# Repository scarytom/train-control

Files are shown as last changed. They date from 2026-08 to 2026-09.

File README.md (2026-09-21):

# Train Controller (slot-car hand controller)

We are designing a more ergonomic hand controller for working with minature railway locomotives.  This is an improvement
over the [4QD RBT Hand Control](https://www.4qd.co.uk/product/hand-control-box/).

# Enclosure Design (3D Print) and Assembly
## Files

| File | Purpose | Status |
|---|---|---|
| `design.scad` | **Current working model.** Self-contained (no external files). | Active — work here |
| `profiles/body_outline.dxf` | Ergonomic outline projected from `Left.stl`. Used by `design2.scad`. | Input for v2 |
| `ref/Left.stl`, `ref/Right.stl` | Example printed controller shells (ground-truth ergonomic shape). | Reference |
| `ref/controller3.jpg` | Photo of the reference controller. | Reference |
| `renders/` | Rendered preview PNGs. | Build output |

Recommended: continue in **`design.scad`** — it is a single self-contained file.

## Coordinate convention

- **X** = up/down along the controller length. Top at **−X**, grip / butt at **+X**.
- **Z** = forward / backward.  Front at **+Z**, rear at **−Z**
- **Y** = thickness. The two shell halves separate along **Y**; the profile is centred on Y = 0.

## Face identification

The controller outline has **10 named faces**, each identified by a colour in the
diagram below. This terminology is used throughout the documentation and code.

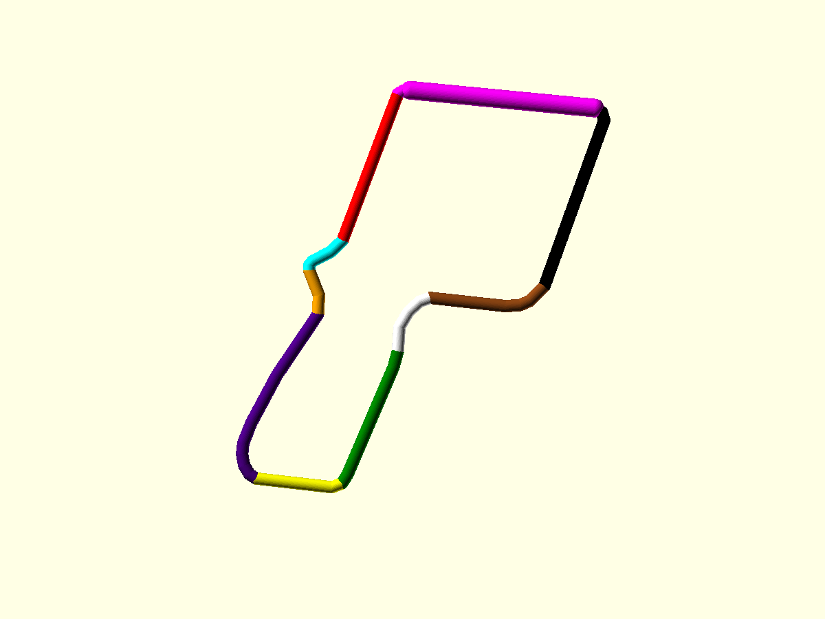
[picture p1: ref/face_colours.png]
Face Colours


| Face | Colour | Points | Description |
|---|---|---|---|
| 1 | Red | 0→1 | **Rear Face** — back of the controller body |
| 2 | Cyan | 1→5 | **Tang Top** — upper surface of the tang |
| 3 | Orange | 5→7 | **Tang Bottom** — lower surface of the tang |
| 4 | Indigo | 7→14 | **Grip Rear** — back of the pistol grip |
| 5 | Yellow | 14→16  | **Grip Butt** — bottom/base of the grip |
| 6 | Green | 16→19  | **Grip Front** — front of the pistol grip |
| 7 | White | 19→23  | **Trigger Throat** — opening where the trigger exits |
| 8 | Brown | 23→27  | **Underbelly** — underside of the controller body |
| 9 | Black | 27→30  | **Front Face** — front of the controller body |
| 10 | Magenta | 30→0 | **Instrument Panel** — raised surface for switches/meter |

The **Instrument Panel** (magenta) is pushed outward by `button_clearance = 20 mm`
along its face normal to provide room for internal components. The adjacent corner
fillets (points 28–29 and 31–33, 0) move with it to blend smoothly into the body.

## What the model produces

`design.scad` produces a complete, print-ready **hollow two-part shell** with
trigger, internal pot mount, control panel and connector:

1. **Ergonomic outline** — the real pistol-grip silhouette, embedded as an inline
   `polygon()` (`outline_points` / `outline_paths`), simplified from `Left.stl`.
2. **Slot removed** — the original finger slot has been deleted from the outline
   (its path is no longer referenced). Its location is preserved as data (see below).
3. **Thickness taper (Y)** — `head_thick = 60 mm` at the head, tapering to
   `grip_thick = 25 mm` at the grip, via `thickness_mask()`.
4. **Raised Instrument Panel** — the angled ~50° face (the switch/meter-mounting
   surface, outline edge 30→31) is pushed outward along its own normal by
   `button_clearance = 20 mm`, with its corner fillets travelling with it so it
   blends smoothly into the body.
5. **Rounded edges** — the whole body is softened via `minkowski()` with a
   sphere of radius `grip_round = 3 mm`, so the edges the hand wraps are
   comfortable. Set `grip_round = 0` to disable (see speed note below).
6. **Hollow shell** — the body is hollowed to a uniform `wall = 1.5 mm` shell
   (`inner_cavity()` = the outer surface shrunk inward by `wall`;
   `body_hollow()` = `body_solid()` minus that cavity). Verified 1.5 mm walls.
7. **Split into two halves** — `left_shell()` / `right_shell()` clip the hollow
   body at the Y = 0 plane into two mating halves.
8. **Mate features** — six perimeter M3 bolt bosses (through-bolt + hex nut
   trap) with alignment spigots
9. **Linear pot mount** — a solid box platform in the LEFT half holding a Bourns
   PTA2043 (35.5×9.5×6.5 mm) along the recorded diagonal pot axis. The pot sits
   on top of the mounting box (30×15×18 mm) with 4 blind holes for the fixing
   pins (1.6 mm diameter, 4 mm deep), positioned per the datasheet (22.8 mm and
   25.2 mm centre-to-centre spacing). Two side clips grip the pot's top edges to
   prevent lifting. Ends are open for wire soldering access.
10. **Trigger + pivot + return spring** — a trigger lever (`trigger_lever()`)
    pivoting at `pivot_pos`: a BENT finger blade exiting the throat up-and-forward
    at ~45°, then curling back to a finger tip near `[0, 30]`, and an actuator arm
    with an elongated fork slot driving the pot lever.
    The pivot pin and spring anchor share a 3 mm rod (`rod_dia`), each captured
    in blind-bore bosses. A return spring hooks a hole in the armature and a
    rod in a body anchor boss, pulling the trigger to rest.
11. **Instrument panel** — holes drilled into the **Instrument Panel** along its normal
    via a face frame built from the face's four corners (`panel_face_place`). The
    LEFT half has four 6 mm toggle holes (master on its own row; horn / reverse /
    lights in a row at 15 mm pitch); the RIGHT half has the LED battery-meter
    cutout (square 25.5 × 2.2 mm slot + two 3.5 mm end holes, 33 mm apart). All
    clear of the bolt bosses.
12. **Thumb button** — a 6 mm push-button hole (`thumb_button_cut()`) on the
    **tang top** at `thumb_pos`, drilled along the local surface normal
    (`thumb_normal`). It sits ON the Y = 0 split, so it is halved into a matching
    semicircle in each shell.
13. **DX16 connector** — a panel-mount aviation socket (16 mm hole, 7 mm thread,
    inner retaining nut) on the **Grip Butt** at `cable_pos`, drilled
    along the local surface normal. Because a threaded connector needs a flat
    full-thickness seat (not a split semicircle), it uses a moulded round **pad**
    (`connector_pad()`, Ø19, 2 mm proud + 3 mm in) on the LEFT shell that crosses
    the seam so the hole stays centred; the RIGHT shell has a matching recess
    (`connector_recess()`). An internal **reinforcing collar**
    (`connector_reinforce()`, LEFT half only) thickens the wall around the socket
    for strength. The Ø16 bore (`connector_hole()`) cuts through both halves.

### Key parameters (top of `design.scad`)

- `grip_thick`, `head_thick` — body thickness (Y) at grip / head.
- `taper_head_x`, `taper_grip_x` — where the thickness taper starts/ends along X.
- `button_clearance` — how far the Instrument Panel is pushed out (room above the pot).
- `button_face_normal`, `button_move_idx` — direction and which outline points move
  (the Instrument Panel + both corner fillets: `[28,29,30,31,32,33,0]`).
- `grip_round` — edge-rounding radius (mm); `0` disables it.
- `wall` — shell wall thickness (mm).
- `screw_boss_pos` — list of `[X, Z]` boss/bolt locations (currently six).
- `screw_clear_dia`, `screw_boss_dia` — bolt clearance hole / boss diameter.
- `screw_head_dia`, `screw_head_depth` — round bolt-head recess (left face).
- `nut_af`, `nut_depth` — hex nut recess across-flats / depth (right face).
- `spigot_dia`, `spigot_len`, `spigot_clear` — boss alignment spigot / fit.
- `pot_len`, `pot_wid`, `pot_hgt` — PTA2043 body envelope (35.5 / 9.5 / 6.5 mm).
- `pot_box_len`, `pot_box_wid`, `pot_box_hgt` — mounting box platform dimensions (30 / 15 / 18 mm).
- `pot_pin_hole_dia`, `pot_pin_hole_depth` — blind hole for fixing pins (1.6 mm dia, 4 mm deep).
- `pot_clip_thick`, `pot_clip_overlap` — side clip dimensions (1.5 mm thick, 1.5 mm overlap).
- `pot_inset` — how far the pot top sits below the split (armature clearance).
- `pot_shift` — shift along the pot long axis (+ve = toward the back/grip).
- `pot_lever_slot_w` — lever clearance slot width (6.5 mm, matches pot lever).
- `rod_dia` — shared metal-rod diameter for BOTH the trigger pivot pin and the
  spring anchor rod (default 3 mm, a common steel dowel / silver-steel size).
- `trigger_thick`, `trigger_hub_dia` — trigger lever thickness / pivot hub.
- `trigger_blade_len`, `trigger_blade_ang` — first blade segment reach/angle out
  of the throat.
- `trigger_blade_knee`, `trigger_blade_tip2` — the bend: knee (near the pivot,
  end of the first segment) and the curled finger tip `[X,Z]` (default `[0,30]`).
- `trigger_arm_aim`, `trigger_arm_extra`, `trigger_arm_w` — actuator arm target,
  extra length, width.
- `trigger_fork_slot`, `trigger_fork_len`, `trigger_fork_pivot_ext` — elongated
  fork slot (width / length / extension toward the pivot) that drives the pot lever.
- `trigger_throat_ext`, `trigger_throat_lowext` — throat cutout swing clearance.
- `pivot_boss_dia`, `pivot_hub_gap`, `pivot_bore_depth` — pivot boss / blind bore.
- `spring_trigger_pos`, `spring_hole_dia` — spring hook hole in the armature.
- `spring_anchor_pos`, `spring_boss_dia`, `spring_bore_depth` — body spring-anchor
  boss + blind bore for the captured rod.
- `ip_TL`, `ip_TR`, `ip_BL`, `ip_BR` — the four corners of the Instrument Panel
  (ground-truth coordinates); the `panel_face_place(u,v)` frame is built from them.
- `toggle_hole_dia`, `panel_drill` — toggle hole diameter / drill depth.
- `toggle_master_u`, `toggle_master_v` — master switch position (upper row).
- `toggle_row_u`, `toggle_row_v` — horn / reverse / lights positions (lower row).
- `meter_slot_l`, `meter_slot_w`, `meter_end_holes`, `meter_hole_span`,
  `meter_u`, `meter_v_right` — LED battery-meter slot + end-hole geometry / placement.
- `thumb_pos`, `thumb_dia`, `thumb_normal`, `thumb_drill` — thumb-button hole
  centre `[X,Z]`, diameter (6 mm), local surface normal, and drill depth. The
  hole is centred on Y = 0 so it splits into a semicircle per shell.
- `cable_pos`, `cable_normal` — DX16 connector centre `[X,Z]` on the grip butt
  and its local outward surface normal (the drilling / socket axis).
- `conn_hole_dia`, `conn_pad_dia`, `conn_pad_proud`, `conn_pad_y` — DX16 bore
  (16 mm), pad diameter (19 mm), pad proud height, and total pad length.
- `conn_reinf_dia`, `conn_reinf_len` — internal reinforcing collar diameter /
  inward depth (LEFT half only). `conn_recess_clear` — right-shell recess fit.
- `part_to_render` — `left_shell`, `right_shell`, `trigger`, `export_stl`,
  `partial_exploded_assembly`, `closed_assembly`, `exploded_assembly`.

## How to render

From the project root (paths in the file are relative):

```bash
# quick preview (isometric)
openscad -o renders/iso.png --camera=200,-260,150,-5,0,5 --viewall design.scad

# clean orthographic side view (the ergonomic silhouette)
openscad -o renders/side.png --camera=0,300,0,0,0,0 --viewall --projection=o design.scad

# export the print-ready plate (all three parts, print orientation)
openscad -o stl/export_plate.stl --render -D 'part_to_render="export_stl"' design.scad
```

Tip: `--viewall` frames the model automatically; `--projection=o` gives a true
orthographic view (best for judging profiles).

## Assembly & fasteners

- **Bolts:** six M3 through-bolts (`screw_boss_pos`). Each drops into a round
  head recess on the LEFT outer face, through a 3.4 mm clearance hole, into a
  hex **nut trap** (`nut_af = 5.5 mm` A/F) on the RIGHT face. Right-half
  **spigots** register into left-half counterbores for alignment.
- **Rods:** the trigger pivot pin and the spring anchor share one `rod_dia`
  (3 mm) steel rod, each captured in blind-bore bosses.
- **Print plate:** `part_to_render = "export_stl"` lays all three parts on the
  bed in print orientation (left shell −90°, right shell / trigger +90° about X),
  each on `Z = 0` and spaced along Y. Each part is manifold (`Simple: yes`).
  The `left_shell` / `right_shell` / `trigger` modes export a single part in its
  native orientation.

## Notes

- The inline outline is a simplified version of the DXF (49 points via
  Douglas-Peucker, ~0.3 mm tolerance). Regenerate with a tighter tolerance if a
  closer match to the original mesh is ever needed.
- The pot axis is diagonal (~−51°); the slide pot mounts at that angle.
- Edge rounding uses `minkowski()`, which needs a full CGAL render
  (`openscad --render ...`) and is slow (~15–30 s). For fast iteration while
  working on other features, set `grip_round = 0`, then restore it for final
  renders / export.

## TODO

### ~~1. Identify the faces~~ ✓ DONE
See [Face identification](#face-identification) section above.

### ~~2. Narrower gap for the trigger lever~~ ✓ DONE
- The trigger lever is 6mm thick (`trigger_thick`), with 0.5mm clearance per side
- Total slot width = 7mm (set by `pivot_hub_gap = trigger_thick/2 + 0.5`)

### ~~3. Refine the pot mounting~~ ✓ DONE
- ✓ Updated pot dimensions to PTA2043: 35.5mm × 9.5mm × 6.5mm
- ✓ Created solid box platform (30mm × 15mm × 18mm) with 4 blind holes for fixing pins
- ✓ Pin holes are 1.6mm diameter (tight fit for 1.5mm pins), 4mm deep
- ✓ Pin spacing: 22.8mm left side, 25.2mm right side (per datasheet)
- ✓ Added 4 clips (3mm wide each) to grip the pot top and prevent lifting
- ✓ Ends remain open for wire soldering access
- ✓ Pot moved 6mm closer to front (black) face (`pot_shift` changed to -1)
- ✓ Trigger pivot moved to align with pot position
- ✓ Trigger blade straightened with bend at [-10, 10], tip at [0, 25]
- ✓ Throat cutout extended 5mm toward black face

### ~~4. move the hub for the trigger spring~~ ✓ DONE
- ✓ Moved spring anchor to [-24.5, -38.5] - near rear (red) face, in line with pot end

### ~~5. Horn buttons~~ ✓ DONE
- ✓ Added 2 horn buttons, one on each side of the controller
- ✓ 5mm mounting holes (per BOM)
- ✓ Mounted on the rear (red) face, close to the tang top (cyan) face
- ✓ Position: [-6, -32] X,Z with Y offset of ±11mm

### ~~6. power switch~~ ✓ DONE
- ✓ Changed from toggle to slide switch
- ✓ 2x 2.5mm fixing holes, 19mm centre-to-centre
- ✓ 4.5mm x 10mm central slot
- ✓ Positioned on its own on the left side of the Instrument Panel

### ~~7. lights / reverse switch~~ ✓ DONE
- ✓ Reduced from 3 toggles to 2 (removed horn select switch)
- ✓ Toggles now occupy top and bottom positions (middle hole removed)
- ✓ Updated hole size to 6.5mm (per BOM)
- ✓ Added 2.5mm locking lug hole, 6.5mm above each main hole

### ~~8. Shorten trigger slightly~~ ✓ DONE
- ✓ Trigger blade shortened by 5mm (from 25mm to 20mm)

### ~~9. Trigger slot.~~ ✓ DONE
- ✓ Trigger fork slot widened to 6.5mm (was 4.5mm)
- ✓ Slot length reduced to 2.5mm (was 6mm)

### ~~10. Grip size~~ ✓ DONE
- ✓ Extended grip by 25mm toward the butt (yellow) face
- ✓ Adjusted screw boss positions for longer grip

### ~~11. socket mounting~~ ✓ DONE
- ✓ Replaced round connector pad with square slot for 24mm x 20mm metal plate
- ✓ Slot includes 1.3mm clearance for plate thickness
- ✓ Inner cavity 22mm x 19mm x 8mm for connector body
- ✓ Thickened butt wall to 6mm to accommodate slot

### ~~12. cable tidy~~ ✓ DONE
- ✓ Added 4 cable tie eyes (half-torus loops) on inner walls of both shells
- ✓ Eyes positioned along cable route from butt to head, away from trigger
- ✓ Eyes use thickness_at_x() function to position correctly in tapered regions
- feel free to suggest other cable management solutions that might work better

### ~~13. button caps~~ ✓ DONE
- ✓ Created button_cap() module with rounded donut-rim top for comfort
- ✓ Friction-fit socket for 2.5mm button stem, 3mm deep
- ✓ Test plate with 8 caps at 4 hole sizes (2.3, 2.4, 2.5, 2.6mm) for fit testing
- ✓ Render with part_to_render = "button_cap" or "button_cap_test_plate"

### 14. discuss joining the 2 halves
- the joint we have between the 2 halves gives some flex around the joint, particularly on front (black) face
- discuss ways to improve the joint

# Circuit Design and Parts

## Circuit References
https://www.4qd.co.uk/docs/din-socket-wiring/
https://www.4qd.co.uk/docs/rbt-plug-alignment/
https://www.4qd.co.uk/docs/rbt-circuit-diagram/

## BOM
### DPST main on/off switch
- DPDT 2-Position On-On Mini Slide Switch
- https://www.bitsboxuk.com/index.php?main_page=product_info&products_id=869
- 2x 2.5mm fixing holes 19mm centre-to-centre
- 4.5mm x 10mm slot central longways between fixing holes 

### SPST lights switch
- multicomp 1MS2T6B11M1QE Flat Toggle Switch, SPDT
- https://cpc.farnell.com/multicomp-pro/1ms1t6b11m1qe/switch-spdt/dp/SW02863
- can substitute Round Toggle Switch, SPST
- https://www.bitsboxuk.com/index.php?main_page=product_info&products_id=872
- 6.5mm mounting hole, with a 2.5mm hole placed 6.5mm above it (centre-to-centre) for the locking lug

### SPST reverse switch
- same as lights switch

### Momentary Horn Buttons
We use two SPDT momentary push buttons in a mechanical interlock.
- multicomp 8MS8P1B05M1QES (has a 2.5mm diameter button)
- https://cpc.farnell.com/multicomp-pro/mc8ms8p1b05m1qes/switch-spdt-on-mom-solder/dp/SW05800
- 5mm mounting hole

### Slide potentiometer for accelerator
- Bourns PTA Range - PTA2043-2010CIB103
- 10k linear single gang slide pot
- https://www.bitsboxuk.com/index.php?main_page=product_info&products_id=3247
- https://www.bourns.com/docs/Product-Datasheets/pta.pdf
- 35.5mm long x 9.5mm wide x 6.5mm deep
- slide has a 20mm range
- slide lever is 10mm tall x 5mm wide x 1.75mm thick
- 4x 1.5mm wide, 3mm tall fixing pins on the underside, a pair on each side
- fixing pins are centre-to-centre 22.8mm apart on the left side, 25.2mm apart on the right side
- wires attach to 0.8mm pins at both ends on the underside, so these must be accessible 

### Diodes
- 1N4001 Rectifier Diode 1A 50V
- https://www.bitsboxuk.com/index.php?main_page=product_info&products_id=1888

### Battery meter (BCM)
- Simple voltage divider – c/f
- https://www.4qd.co.uk/product/battery-condition-meter/
- 2x 3.5mm fixing holes 33mm centre-to-centre
- 25.5mm x 2.2mm slot central longways between fixing holes

### 8-core cable
- 7 x 0.2mm multicore cable
- https://cpc.farnell.com/pro-elec/pelb0640/cable-7-2-8a-unshielded-black/dp/CB22630
- https://www.4qd.co.uk/product/control-cable-multicore/
- https://www.amazon.co.uk/gp/product/B005EHZ6UI
- https://www.bitsboxuk.com/index.php?main_page=product_info&products_id=1496

### 8-pin aviation connectors (GX16)
- https://cpc.farnell.com/pro-signal/av19318/multipole-panel-plug-8p/dp/AV19318
- https://cpc.farnell.com/pro-signal/av19305/multipole-socket-8-pole/dp/AV19305
- https://www.amazon.co.uk/gp/product/B07VNKZB65
- https://www.aliexpress.com/item/1005006731992794.html
- 15mm Cutout diameter

### Pins
- https://www.amazon.co.uk/dp/B0DBYCCZ2J

### Spring
- https://cpc.farnell.com/duratool/d01893/spring-set-200pc/dp/FN02651

### bolts
- https://www.amazon.co.uk/dp/B0DGSY35WC
- https://www.amazon.co.uk/dp/B0D8SG7R6F

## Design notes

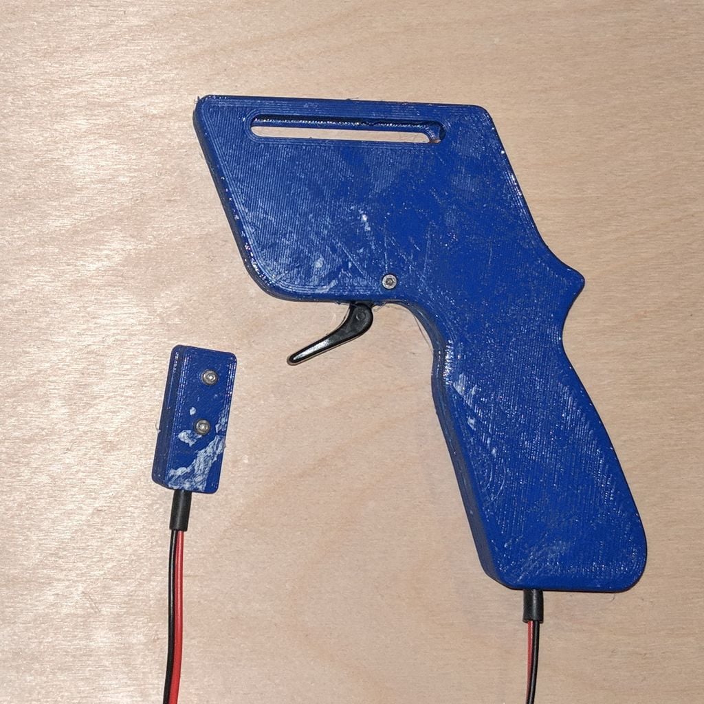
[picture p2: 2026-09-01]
ref/controller3.jpg

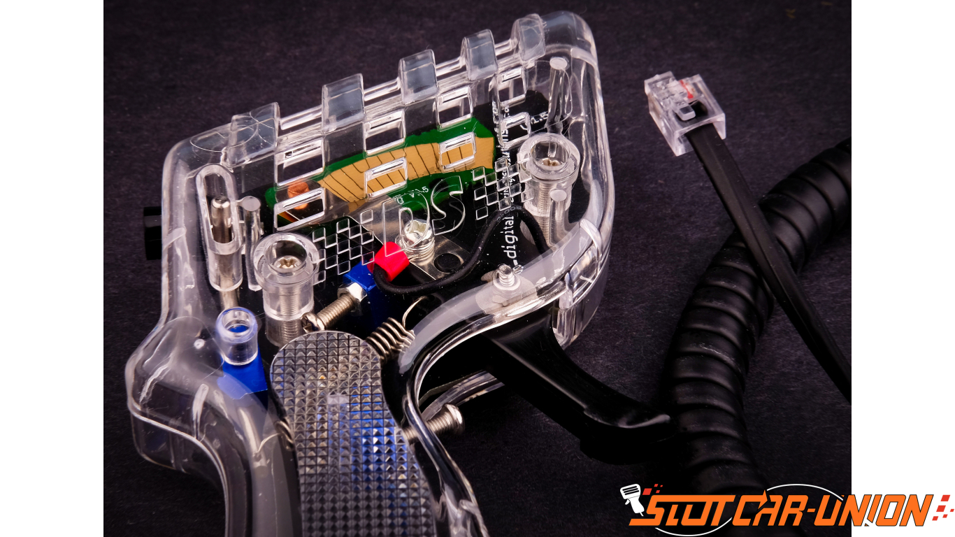
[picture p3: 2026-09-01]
ref/controller2.jpg

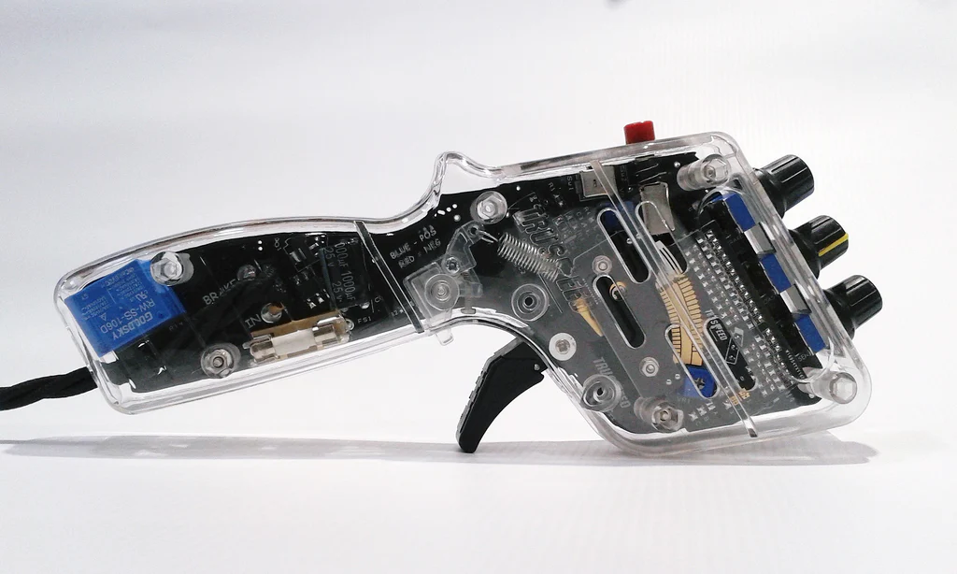
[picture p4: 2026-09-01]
ref/controller.jpg

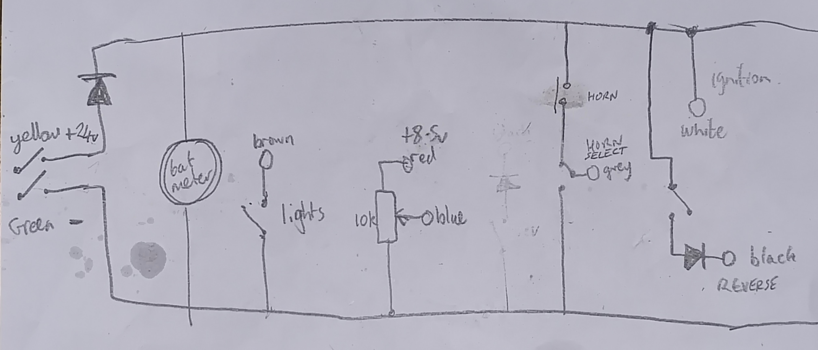
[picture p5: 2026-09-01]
ref/my circuit.jpg

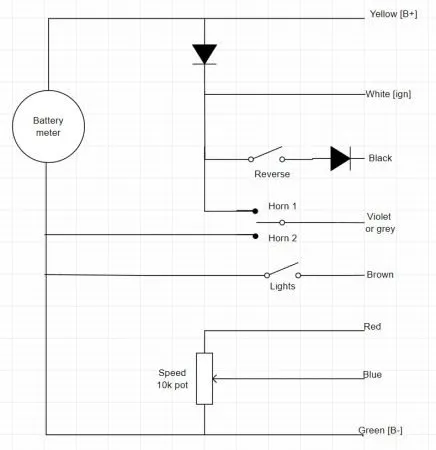
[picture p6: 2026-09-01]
ref/RBT Circuit Diagram.png

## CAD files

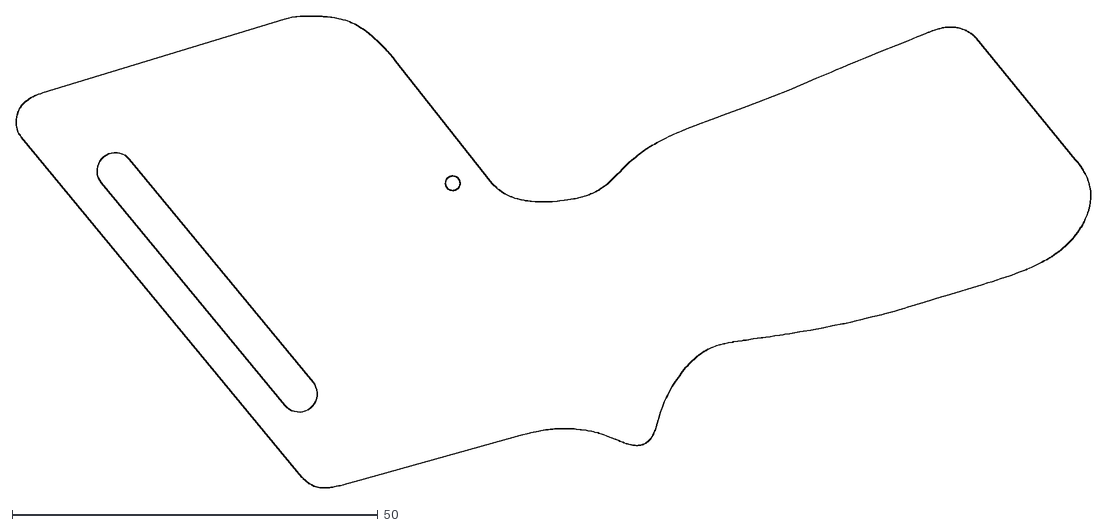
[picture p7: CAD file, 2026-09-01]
profiles/body_outline.dxf
146.9 x 64.5

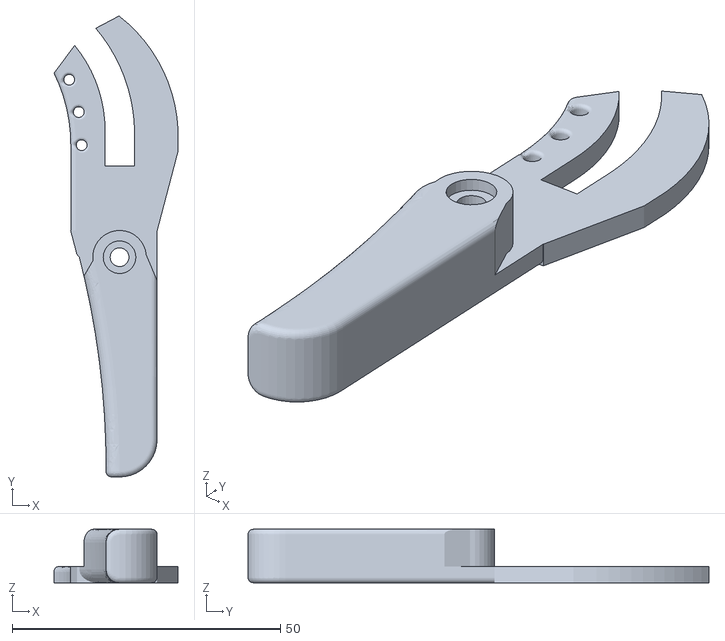
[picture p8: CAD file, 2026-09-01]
ref/trigger.stl
23.1 x 86.0 x 10.00

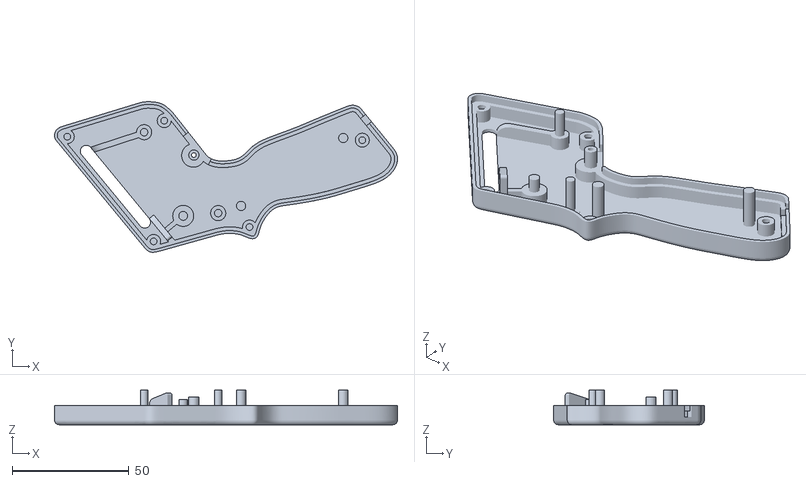
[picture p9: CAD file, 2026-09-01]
ref/Left.stl
146.9 x 64.5 x 14.8

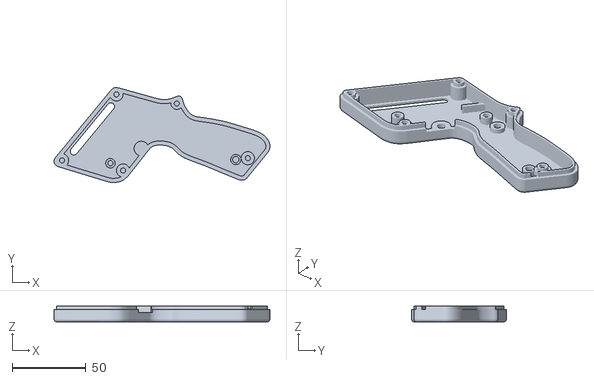
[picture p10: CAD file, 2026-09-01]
ref/Right.stl
146.9 x 64.5 x 10.8

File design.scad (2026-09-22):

// ============================================================
// TRAIN CONTROLLER - self-contained parametric hand controller.
// The ergonomic outline is embedded as a polygon() (simplified from Left.stl).
//
// COORDINATE CONVENTION:
//   X = up/down along the controller length (top at -X, grip/butt at +X)
//   Z = forward/backward (front at +Z, rear at -Z)
//   Y = thickness (the two shell halves separate along Y=0)
// ============================================================

$fn = 48;

// --- RENDER SELECTION ---
// Options: "left_shell", "right_shell", "trigger", "button_caps",
//          "partial_exploded_assembly", "exploded_assembly", "closed_assembly".
part_to_render = "right_shell";

// --- THICKNESS TAPER (Y) : slim grip, broad head ---
grip_thick   = 25.0;   // Y thickness at the grip / trigger region (mm)
head_thick   = 60.0;   // Y thickness at the rear-top head (mm)
taper_head_x = -20.0;  // X at/below which full head_thick is used (head side, -X)
taper_grip_x =   5.0;  // X at/above which grip_thick is used (grip side, +X)

// --- BUTTON CLEARANCE : room above the pot for buttons + wiring ---
// Pushes the angled ~50deg Instrument Panel (outline edge 30->31) OUTWARD along its
// normal by this amount (see button_face_normal / button_move_idx below).
button_clearance = 20.0;   // mm the Instrument Panel is pushed out along its normal

// ------------------------------------------------------------
// 2D OUTLINE (embedded)
// ------------------------------------------------------------
// Ergonomic pistol-grip silhouette in its native X x height plane.
// Points 0-33 = outer body, 34-43 = (former finger slot, now unused),
// 44-48 = small pivot hole. See outline_paths for which are used.
outline_points = [
  [-30.17, -39.54], [0.26, -31.57], [5.49, -31.68], [11.58, -33.66],
  [13.32, -33.58], [14.57, -32.37], [18.05, -24.45], [22.6, -20.38],
  [70.87, -15.85], [87.59, -10.8], [93.85, -8.08], [96.59, -5.88],
  [98.74, -2.77], [99.46, 0.39], [98.97, 2.85], [83.71, 22.07],
  [80.61, 23.47], [77.26, 22.74], [17.33, 8.76], [12.72, 6.1],
  [6.95, 1.06], [1.48, -0.33], [-3.5, -0.13], [-6.68, 1.4],
  [-21.98, 20.46], [-25.57, 23.54], [-28.68, 24.7], [-35.32, 24.67],
  [-71.14, 13.34], [-72.45, 10.9], [-71.77, 8.39], [-33.8, -37.68],
  [-32.1, -39.13], [-30.33, -39.55],
  // finger slot
  [-34.06, -29.16], [-35.75, -28.26], [-60.86, 2.22], [-61.42, 4.05],
  [-60.52, 5.74], [-58.69, 6.3], [-57, 5.4], [-31.89, -25.08],
  [-31.52, -27.67], [-33.66, -29.17],
  // small pivot hole
  [-12.9, 1.13], [-13.78, 2.14], [-12.76, 3.11], [-11.79, 2.09],
  [-12.81, 1.12]
];

// path[0] = outer body only. Points 34-48 (former finger slot + pivot marker)
// are intentionally not referenced; the pivot is bored later (see pivot_pos).
outline_paths = [
  [0, 1, 2, 3, 4, 5, 6, 7, 8, 9, 10, 11, 12, 13, 14, 15, 16, 17, 18, 19,
   20, 21, 22, 23, 24, 25, 26, 27, 28, 29, 30, 31, 32, 33]
];

module outline_2d() {
    polygon(points = outline_points, paths = outline_paths);
}

// Outline with the Instrument Panel pushed OUTWARD along its normal by
// button_clearance. The face is moved together with its corner-fillet points
// (rear {28,29,30}, front {31,32,33,0}) so the curves travel with it and the
// adjacent long edges re-angle smoothly instead of kinking.
button_face_normal = [-0.772, -0.636];  // outward normal of edge 30->31 (~ -140.5 deg)
button_move_idx    = [28, 29, 30, 31, 32, 33, 0];  // Instrument Panel + both corner fillets

function _moved(i) =
    (search(i, button_move_idx) != [])
        ? [ outline_points[i][0] + button_face_normal[0] * button_clearance,
            outline_points[i][1] + button_face_normal[1] * button_clearance ]
        : outline_points[i];

raised_outline_points = [ for (i = [0 : len(outline_points) - 1]) _moved(i) ];

module raised_outline_2d() {
    polygon(points = raised_outline_points, paths = outline_paths);
}

// ------------------------------------------------------------
// LINEAR POT LOCATION (was the original finger slot)
// ------------------------------------------------------------
// The finger slot we removed marks exactly where the internal slide
// potentiometer mounts. We preserve its geometry here as data so the future
// pot mount/pocket can be placed on the same axis. Coordinates are in the
// outline's X (length) x Z (height) plane (pot lies in the X-Z plane, centred
// on Y=0). Derived from the original slot polygon points.
pot_axis_rear  = [-59.7,  4.7];   // rear-upper end of the slot centerline [X, Z]
pot_axis_front = [-33.4, -27.9];  // front-lower end of the slot centerline [X, Z]
pot_axis_len   = 41.9;            // centerline length (mm)
pot_axis_angle = -51.1;           // angle of the slot from +X in the X-Z plane (deg)
pot_axis_mid   = [ (pot_axis_rear[0]+pot_axis_front[0])/2,
                   (pot_axis_rear[1]+pot_axis_front[1])/2 ];  // = ~[-46.5, -11.6]

// ------------------------------------------------------------
// LINEAR POT MOUNT (Bourns PTA2043-2010CIB103)
// ------------------------------------------------------------
// Pot specs from BOM:
//   Body: 35.5mm long x 9.5mm wide x 6.5mm deep
//   Lever: 10mm tall x 5mm wide x 1.75mm thick
//   Travel: 20mm
//   Fixing pins: 4x 1.5mm wide x 3mm tall on underside
//     - Left side pair: 22.8mm centre-to-centre
//     - Right side pair: 25.2mm centre-to-centre
//   Wire pins: 0.8mm at both ends on underside

// Pot body dimensions
pot_len = 35.5;  // body length (mm)
pot_wid = 9.5;   // body width (mm)
pot_hgt = 6.5;   // body height (mm)

// Mounting platform dimensions
pot_box_len = 30.0;  // platform length along pot axis (mm)
pot_box_wid = 15.0;  // platform width across pot axis (mm)
pot_box_hgt = 18.0;  // platform height in Y (mm)

// Fixing pin holes (4 pins on underside of pot)
pot_pin_dia   = 1.6;   // hole diameter - tight fit for 1.5mm pins (mm)
pot_pin_depth = 4.0;   // hole depth (mm)
pot_pin_left_spacing  = 22.8;  // centre-to-centre spacing on left side (mm)
pot_pin_right_spacing = 25.2;  // centre-to-centre spacing on right side (mm)
pot_pin_z_offset = 3.0;  // distance from pot centreline to pin rows (mm)

// Position adjustment
pot_inset = 5.0;   // how far the pot TOP sits below the split (into +Y)
pot_shift = -1.0;  // shift along pot axis (+ve = toward back/grip)

// Places children into the pot's local frame: origin at pot_axis_mid (Y=0),
// local +X along the pot axis. Rotation about global Y by -pot_axis_angle
// maps local X onto the axis direction in the X-Z plane.
module pot_place() {
    translate([pot_axis_mid[0], 0, pot_axis_mid[1]])
        rotate([0, -pot_axis_angle, 0])
            translate([pot_shift, 0, 0])
                children();
}

// The mounting platform - solid block that the pot sits on top of.
// Pot top is at Y = pot_inset, pot bottom at Y = pot_inset + pot_hgt.
// Platform extends from pot bottom downward into +Y.
module pot_platform() {
    pot_place()
        translate([0, pot_inset + pot_hgt + pot_box_hgt/2, 0])
            cube([pot_box_len, pot_box_hgt, pot_box_wid], center = true);
}

// Blind holes for the 4 fixing pins on underside of pot.
// Pins are at pot bottom (Y = pot_inset + pot_hgt), holes go down into platform.
module pot_pin_holes() {
    pot_place() {
        pin_top = pot_inset + pot_hgt;  // top of platform / bottom of pot
        
        // Left side pins (-Z): 22.8mm apart in X
        translate([-pot_pin_left_spacing/2, pin_top + pot_pin_depth, -pot_pin_z_offset])
            rotate([90, 0, 0])
                cylinder(h = pot_pin_depth + 1, d = pot_pin_dia);
        translate([ pot_pin_left_spacing/2, pin_top + pot_pin_depth, -pot_pin_z_offset])
            rotate([90, 0, 0])
                cylinder(h = pot_pin_depth + 1, d = pot_pin_dia);
        
        // Right side pins (+Z): 25.2mm apart in X
        translate([-pot_pin_right_spacing/2, pin_top + pot_pin_depth, pot_pin_z_offset])
            rotate([90, 0, 0])
                cylinder(h = pot_pin_depth + 1, d = pot_pin_dia);
        translate([ pot_pin_right_spacing/2, pin_top + pot_pin_depth, pot_pin_z_offset])
            rotate([90, 0, 0])
                cylinder(h = pot_pin_depth + 1, d = pot_pin_dia);
    }
}

// Clip to grip pot top and prevent lifting
pot_clip_thick = 1.5;    // clip wall thickness (mm)
pot_clip_overlap = 0.5;  // how far clip extends over pot top (mm)
pot_clip_gap = 0.3;      // clearance around pot body (mm)
pot_clip_len = 3.0;      // clip length along pot axis (mm)
pot_clip_spacing = 20.0; // spacing between clips on same side (mm)
pot_clip_vert_thick = 2.5;  // vertical part thickness (mm)
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

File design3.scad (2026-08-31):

// ============================================================
// TRAIN CONTROLLER - self-contained parametric hand controller.
// The ergonomic outline is embedded as a polygon() (simplified from Left.stl).
//
// COORDINATE CONVENTION:
//   X = controller length (head/nose at -X, grip/butt at +X)
//   Z = up/down (silhouette height)
//   Y = thickness (the two shell halves separate along Y=0)
// ============================================================

$fn = 48;

// --- RENDER SELECTION ---
// Options: "left_shell", "right_shell", "trigger", "export_stl",
//          "partial_exploded_assembly", "exploded_assembly", "closed_assembly".
part_to_render = "partial_exploded_assembly";

// --- THICKNESS TAPER (Y) : slim grip, broad head ---
grip_thick   = 25.0;   // Y thickness at the grip / trigger region (mm)
head_thick   = 60.0;   // Y thickness at the rear-top head (mm)
taper_head_x = -20.0;  // X at/below which full head_thick is used (head side, -X)
taper_grip_x =   5.0;  // X at/above which grip_thick is used (grip side, +X)

// --- BUTTON CLEARANCE : room above the pot for buttons + wiring ---
// Pushes the angled ~50deg button face (outline edge 30->31) OUTWARD along its
// normal by this amount (see button_face_normal / button_move_idx below).
button_clearance = 20.0;   // mm the button face is pushed out along its normal

// ------------------------------------------------------------
// 2D OUTLINE (embedded)
// ------------------------------------------------------------
// Ergonomic pistol-grip silhouette in its native X x height plane.
// Points 0-33 = outer body, 34-43 = (former finger slot, now unused),
// 44-48 = small pivot hole. See outline_paths for which are used.
outline_points = [
  [-30.17, -39.54], [0.26, -31.57], [5.49, -31.68], [11.58, -33.66],
  [13.32, -33.58], [14.57, -32.37], [18.05, -24.45], [22.6, -20.38],
  [45.87, -15.85], [62.59, -10.8], [68.85, -8.08], [71.59, -5.88],
  [73.74, -2.77], [74.46, 0.39], [73.97, 2.85], [58.71, 22.07],
  [55.61, 23.47], [52.26, 22.74], [17.33, 8.76], [12.72, 6.1],
  [6.95, 1.06], [1.48, -0.33], [-3.5, -0.13], [-6.68, 1.4],
  [-21.98, 20.46], [-25.57, 23.54], [-28.68, 24.7], [-35.32, 24.67],
  [-71.14, 13.34], [-72.45, 10.9], [-71.77, 8.39], [-33.8, -37.68],
  [-32.1, -39.13], [-30.33, -39.55],
  // finger slot
  [-34.06, -29.16], [-35.75, -28.26], [-60.86, 2.22], [-61.42, 4.05],
  [-60.52, 5.74], [-58.69, 6.3], [-57, 5.4], [-31.89, -25.08],
  [-31.52, -27.67], [-33.66, -29.17],
  // small pivot hole
  [-12.9, 1.13], [-13.78, 2.14], [-12.76, 3.11], [-11.79, 2.09],
  [-12.81, 1.12]
];

// path[0] = outer body only. Points 34-48 (former finger slot + pivot marker)
// are intentionally not referenced; the pivot is bored later (see pivot_pos).
outline_paths = [
  [0, 1, 2, 3, 4, 5, 6, 7, 8, 9, 10, 11, 12, 13, 14, 15, 16, 17, 18, 19,
   20, 21, 22, 23, 24, 25, 26, 27, 28, 29, 30, 31, 32, 33]
];

module outline_2d() {
    polygon(points = outline_points, paths = outline_paths);
}

// Outline with the blue button face pushed OUTWARD along its normal by
// button_clearance. The face is moved together with its corner-fillet points
// (rear {28,29,30}, front {31,32,33,0}) so the curves travel with it and the
// adjacent long edges re-angle smoothly instead of kinking.
button_face_normal = [-0.772, -0.636];  // outward normal of edge 30->31 (~ -140.5 deg)
button_move_idx    = [28, 29, 30, 31, 32, 33, 0];  // blue face + both corner fillets

function _moved(i) =
    (search(i, button_move_idx) != [])
        ? [ outline_points[i][0] + button_face_normal[0] * button_clearance,
            outline_points[i][1] + button_face_normal[1] * button_clearance ]
        : outline_points[i];

raised_outline_points = [ for (i = [0 : len(outline_points) - 1]) _moved(i) ];

module raised_outline_2d() {
    polygon(points = raised_outline_points, paths = outline_paths);
}

// ------------------------------------------------------------
// LINEAR POT LOCATION (was the original finger slot)
// ------------------------------------------------------------
// The finger slot we removed marks exactly where the internal slide
// potentiometer mounts. We preserve its geometry here as data so the future
// pot mount/pocket can be placed on the same axis. Coordinates are in the
// outline's X (length) x Z (height) plane (pot lies in the X-Z plane, centred
// on Y=0). Derived from the original slot polygon points.
pot_axis_rear  = [-59.7,  4.7];   // rear-upper end of the slot centerline [X, Z]
pot_axis_front = [-33.4, -27.9];  // front-lower end of the slot centerline [X, Z]
pot_axis_len   = 41.9;            // centerline length (mm)
pot_axis_angle = -51.1;           // angle of the slot from +X in the X-Z plane (deg)
pot_axis_mid   = [ (pot_axis_rear[0]+pot_axis_front[0])/2,
                   (pot_axis_rear[1]+pot_axis_front[1])/2 ];  // = ~[-46.5, -11.6]

// ------------------------------------------------------------
// LINEAR POT MOUNT (Bourns PTA3043, held directly by the shell — option B)
// ------------------------------------------------------------
// Body envelope 45 (L) x 9 (W) x 6.5 (H) mm, 30 mm travel. The pot lies with:
//   local X = length  -> along the pot axis (pot_axis_angle in the X-Z plane)
//   local Z = width   -> across the axis, in the X-Z plane
//   local Y = height  -> along global Y; the slider LEVER emerges across the
//                        split plane (toward one half).
pot_len    = 45.0;   // body length (mm)
pot_wid    = 9.0;    // body width (mm)
pot_hgt    = 6.5;    // body height (mm) -> along Y
pot_fit    = 0.4;    // clearance around the body in the pocket (mm)
pot_inset  = 5.0;    // how far the pot TOP sits below the split (into +Y), so
                     // the trigger armature can travel past it near Y=0. The
                     // 10 mm lever still reaches across the split.
pot_wall   = 1.6;    // cradle wall thickness around the pocket (mm)
pot_pin_gap = 3.0;   // clearance below the body for solder pins (mm, -Y of body)
pot_lever_slot_w = 6.0;  // width of the lever clearance slot across the split
pot_shift  = 10.0;   // shift along the pot LONG axis; +ve = toward the back of
                     // the controller (grip/butt side), giving the trigger
                     // armature an easier sweep to reach the pot.

// Places children into the pot's local frame: origin at pot_axis_mid (Y=0),
// local +X along the pot axis (local +X points toward the back/grip side of the
// controller, so pot_shift>0 moves the pot toward the back). Rotation about
// global Y by -pot_axis_angle maps local X onto the axis direction in the X-Z plane.
module pot_place() {
    translate([pot_axis_mid[0], 0, pot_axis_mid[1]])
        rotate([0, -pot_axis_angle, 0])
            translate([pot_shift, 0, 0])
                children();
}

// The pot BODY occupies Y in [pot_inset, pot_inset+pot_hgt]; the top of the pot
// is at Y=pot_inset (leaving ~pot_inset mm of clearance at the split for the
// trigger armature). The LEVER (10 mm) protrudes from that face across the
// split into -Y. The pot inserts from the split side and seats against a LEDGE
// at Y = pot_inset+pot_hgt (the cradle floor), so only the lever crosses.
module pot_body_envelope(extra = 0) {
    pot_place()
        translate([0, pot_inset + pot_hgt/2, 0])
            cube([pot_len + 2*extra, pot_hgt + 2*extra, pot_wid + 2*extra], center = true);
}

// Cradle SOLID: a block around the pot that reaches from just below the pot top
// (Y=pot_inset) out to the left half's OUTER wall, so it melds with the side
// wall. Trimmed to the body so it fuses to the shell. Starting at Y=pot_inset
// (not the split) leaves an open channel Y in [0, pot_inset] at the split for
// the trigger armature to travel past. Lives only in the +Y (left) half.
module pot_cradle_solid() {
    y0 = pot_inset;          // cradle top (toward split)
    y1 = 100;                // well beyond the outer wall
    pot_place()
        translate([0, (y0 + y1)/2, 0])
            cube([pot_len + 2*pot_wall, y1 - y0, pot_wid + 2*pot_wall], center = true);
}

// Pocket the pot body drops into (fit clearance), OPEN at the split face and
// stopping at the LEDGE (Y = pot_inset + pot_hgt + fit). Beyond the ledge stays
// solid. Depth spans from -2 (open past the split) up to the ledge.
module pot_pocket() {
    ledge = pot_inset + pot_hgt + pot_fit;   // +Y face of the pocket (the ledge)
    y_lo  = -2;                               // open a bit past the split
    pot_place()
        translate([0, (y_lo + ledge)/2, 0])
            cube([pot_len + 2*pot_fit, ledge - y_lo, pot_wid + 2*pot_fit], center = true);
}
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

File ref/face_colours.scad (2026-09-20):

// Face identification rendering - X-Z plane projection (looking down Y-axis)
// Each face of the controller outline is coloured distinctly
// 10 logical faces identified
// Rotated 135 degrees clockwise so Instrument Panel (Magenta) is at top

$fn = 48;

// The raised outline points (with instrument panel pushed out)
button_clearance = 20.0;
button_face_normal = [-0.772, -0.636];

outline_points = [
  [-30.17, -39.54], [0.26, -31.57], [5.49, -31.68], [11.58, -33.66],
  [13.32, -33.58], [14.57, -32.37], [18.05, -24.45], [22.6, -20.38],
  [45.87, -15.85], [62.59, -10.8], [68.85, -8.08], [71.59, -5.88],
  [73.74, -2.77], [74.46, 0.39], [73.97, 2.85], [58.71, 22.07],
  [55.61, 23.47], [52.26, 22.74], [17.33, 8.76], [12.72, 6.1],
  [6.95, 1.06], [1.48, -0.33], [-3.5, -0.13], [-6.68, 1.4],
  [-21.98, 20.46], [-25.57, 23.54], [-28.68, 24.7], [-35.32, 24.67],
  [-71.14, 13.34], [-72.45, 10.9], [-71.77, 8.39], [-33.8, -37.68],
  [-32.1, -39.13], [-30.33, -39.55]
];

button_move_idx = [28, 29, 30, 31, 32, 33, 0];

function _moved(i) =
    (search(i, button_move_idx) != [])
        ? [ outline_points[i][0] + button_face_normal[0] * button_clearance,
            outline_points[i][1] + button_face_normal[1] * button_clearance ]
        : outline_points[i];

raised_outline_points = [ for (i = [0 : len(outline_points) - 1]) _moved(i) ];

// Draw a thick coloured line between two points
module edge_line(p1, p2, col, thick=2.0) {
    color(col)
    hull() {
        translate([p1[0], 0, p1[1]]) sphere(r=thick);
        translate([p2[0], 0, p2[1]]) sphere(r=thick);
    }
}

// Apply 135 degree clockwise rotation (= -135 degrees)
rotate([0, 135, 0]) {

    // Face 1: REAR FACE (Red) - points 0→1
    for (i = [0:0]) edge_line(raised_outline_points[i], raised_outline_points[i+1], "Red");

    // Face 2: TANG TOP (Cyan) - points 1→5
    for (i = [1:4]) edge_line(raised_outline_points[i], raised_outline_points[i+1], "Cyan");

    // Face 3: TANG BOTTOM (Orange) - points 5→7
    for (i = [5:6]) edge_line(raised_outline_points[i], raised_outline_points[i+1], "Orange");

    // Face 4: GRIP REAR (Indigo) - points 7→14
    for (i = [7:13]) edge_line(raised_outline_points[i], raised_outline_points[i+1], "Indigo");

    // Face 5: GRIP BUTT (Yellow) - points 14→16
    for (i = [14:15]) edge_line(raised_outline_points[i], raised_outline_points[i+1], "Yellow");

    // Face 6: GRIP FRONT (Green) - points 16→19
    for (i = [16:18]) edge_line(raised_outline_points[i], raised_outline_points[i+1], "Green");

    // Face 7: TRIGGER THROAT (White) - points 19→23
    for (i = [19:22]) edge_line(raised_outline_points[i], raised_outline_points[i+1], "White");

    // Face 8: UNDERBELLY (Brown) - points 23→27
    for (i = [23:26]) edge_line(raised_outline_points[i], raised_outline_points[i+1], "SaddleBrown");

    // Face 9: FRONT FACE (Black) - points 27→30
    for (i = [27:29]) edge_line(raised_outline_points[i], raised_outline_points[i+1], "Black");

    // Face 10: INSTRUMENT PANEL (Magenta) - points 30→0
    edge_line(raised_outline_points[30], raised_outline_points[31], "Magenta", 3.0);
    for (i = [31:32]) edge_line(raised_outline_points[i], raised_outline_points[(i+1) % 34], "Magenta");
    edge_line(raised_outline_points[33], raised_outline_points[0], "Magenta");
}

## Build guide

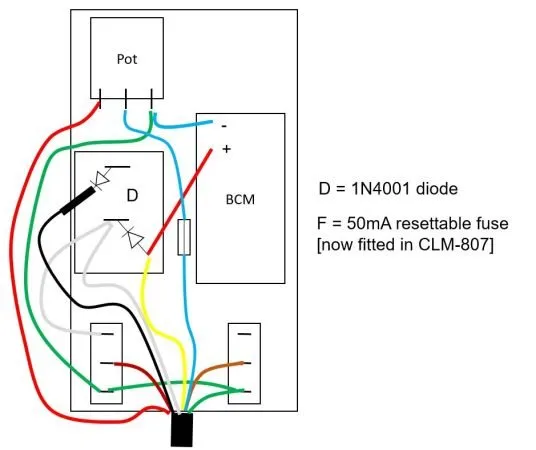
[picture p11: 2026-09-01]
ref/RBT Physical Wiring.png

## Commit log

2026-08-30 rounding corners
    [design3.scad]
2026-08-30 hollow out and split into two halves
    [design3.scad]
2026-08-31 add bosses for screwing together
    [design3.scad]
2026-08-31 bolts to go all the way through
    [design3.scad]
2026-08-31 track README too
2026-08-31 pot cradle
    [design3.scad]
2026-08-31 considering trigger
    [design3.scad]
2026-08-31 trigger progress
    [design3.scad]
2026-08-31 trigger complete
    [design3.scad]
2026-08-31 control panel
    [design3.scad]
2026-08-31 thumb button
    [design3.scad]
2026-08-31 cable exit
    [design3.scad]
2026-08-31 don't foul the boss
    [design3.scad]
2026-08-31 trigger shape
    [design3.scad]
2026-08-31 render all parts for STL export
    [design3.scad]
2026-08-31 remove redundant code
    [design3.scad]
2026-08-31 make a bigger hole for a GX16 Aviation Connector
    [design3.scad]
2026-09-01 old reference material, for posterity
    [Left.stl, Right.stl, body_outline.dxf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]
2026-09-01 shoot old designs
    [design.scad, design2.scad]
2026-09-01 clean filename
    [design.scad]
2026-09-01 include circuit thoughts
2026-09-01 my fag-packet circuit
2026-09-07 BOM thoughts
2026-09-18 BOM refinements and dimensions
2026-09-20 agree on nomenclature
    [face_colours.scad]
2026-09-20 update design.scad with new naming conventions
    [design.scad]
2026-09-20 clarify trigger gap I measure it at 8mm, but the code is definitely calculating 7mm... strange
    [design.scad]
2026-09-20 new pot mounting
    [design.scad]
2026-09-20 trigger adjustments done
    [design.scad]
2026-09-20 spring anchor
    [design.scad]
2026-09-20 horn buttons
    [design.scad]
2026-09-20 power switch
    [design.scad]
2026-09-20 toggle switches
    [design.scad]
2026-09-20 fork slot adjustment
    [design.scad]
2026-09-21 redo cable entrance to accept a plate.
    [design.scad]
2026-09-21 beef up the screw bosses
    [design.scad]
2026-09-21 cable tidies
    [design.scad]
2026-09-21 minor boss adjustment
    [design.scad]
2026-09-21 some button caps
    [design.scad]
2026-09-21 button caps done
    [design.scad]
2026-09-22 improve view of trigger
    [design.scad]
2026-09-22 tweak bosses
    [design.scad]
2026-09-22 tidy execution options
    [design.scad]
2026-09-22 ensure the cable ties merge with the walls.
    [design.scad]
